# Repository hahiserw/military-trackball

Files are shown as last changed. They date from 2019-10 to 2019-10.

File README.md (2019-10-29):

# Military trackball

## Main document - main.pdf

## Youtube demo
demo01 (http://www.youtube.com/watch?v=cAlvmEIusnU)
demo02 (http://www.youtube.com/watch?v=nhbZiIEDlQE)

## Gallery

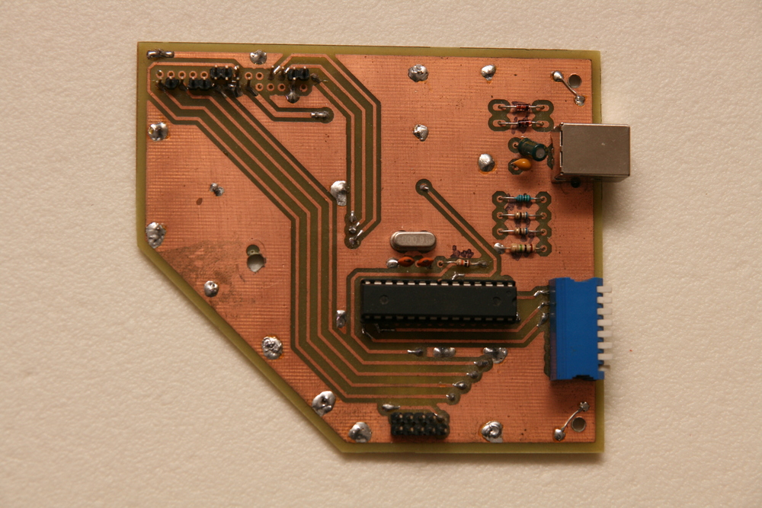
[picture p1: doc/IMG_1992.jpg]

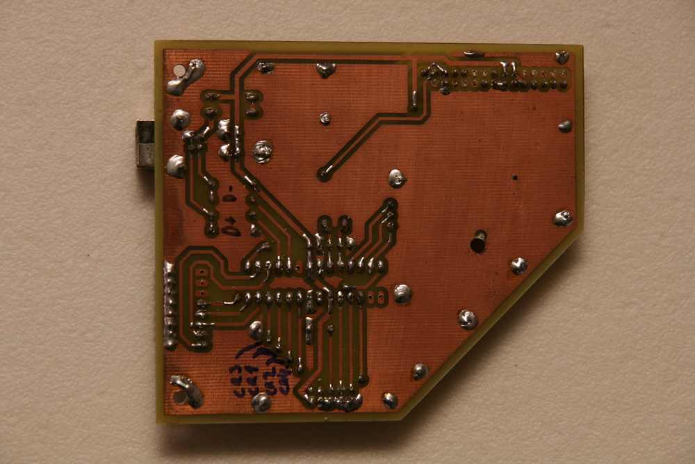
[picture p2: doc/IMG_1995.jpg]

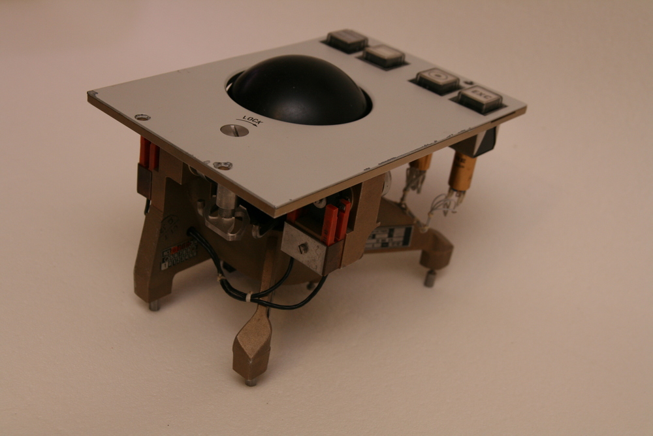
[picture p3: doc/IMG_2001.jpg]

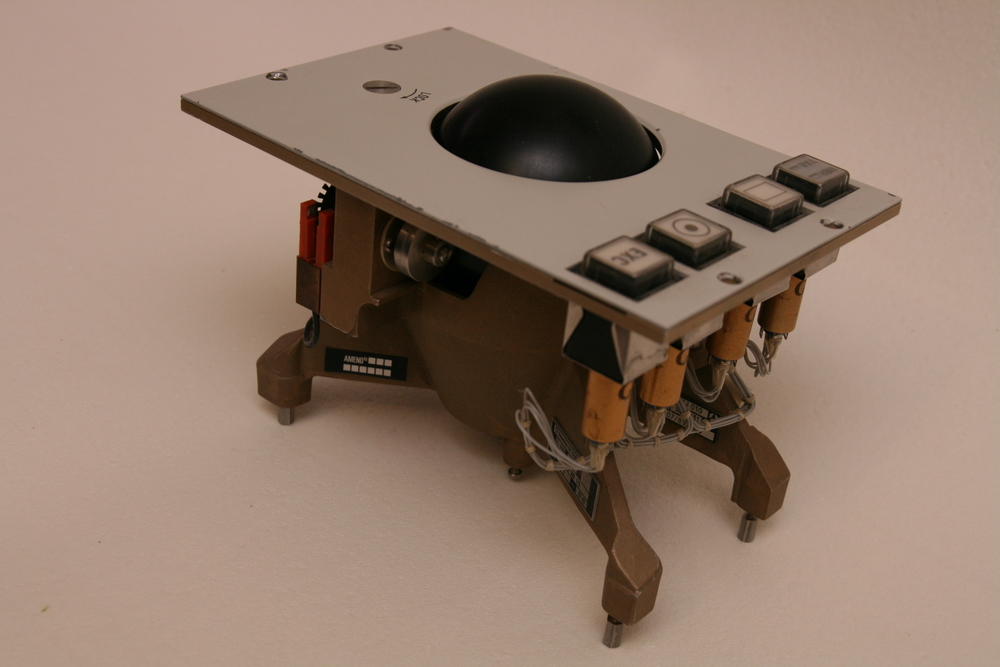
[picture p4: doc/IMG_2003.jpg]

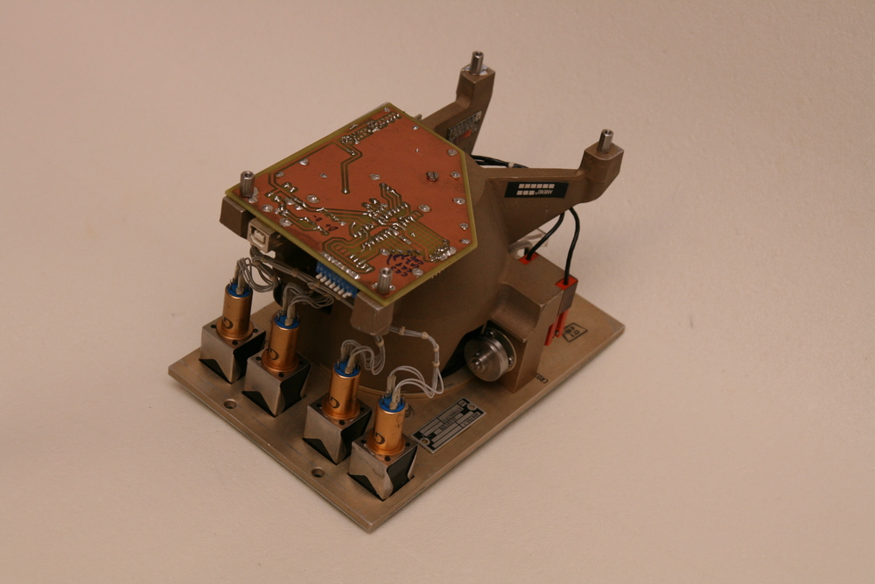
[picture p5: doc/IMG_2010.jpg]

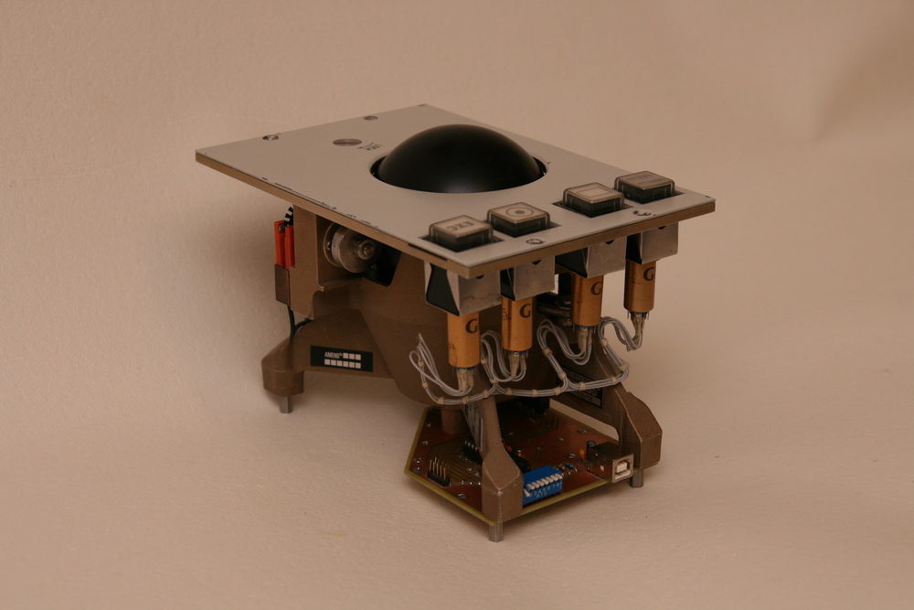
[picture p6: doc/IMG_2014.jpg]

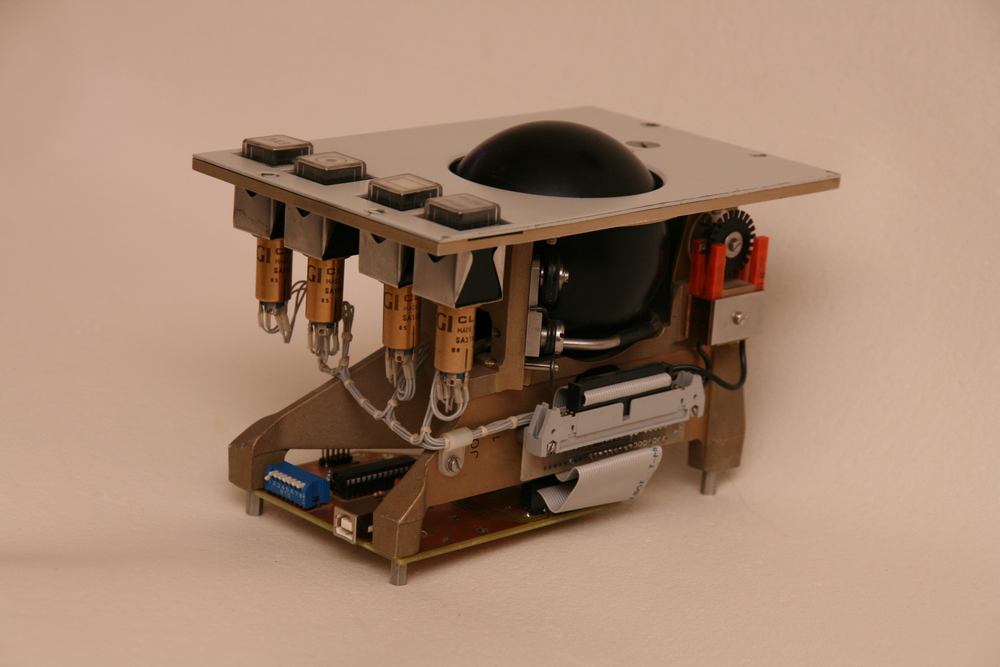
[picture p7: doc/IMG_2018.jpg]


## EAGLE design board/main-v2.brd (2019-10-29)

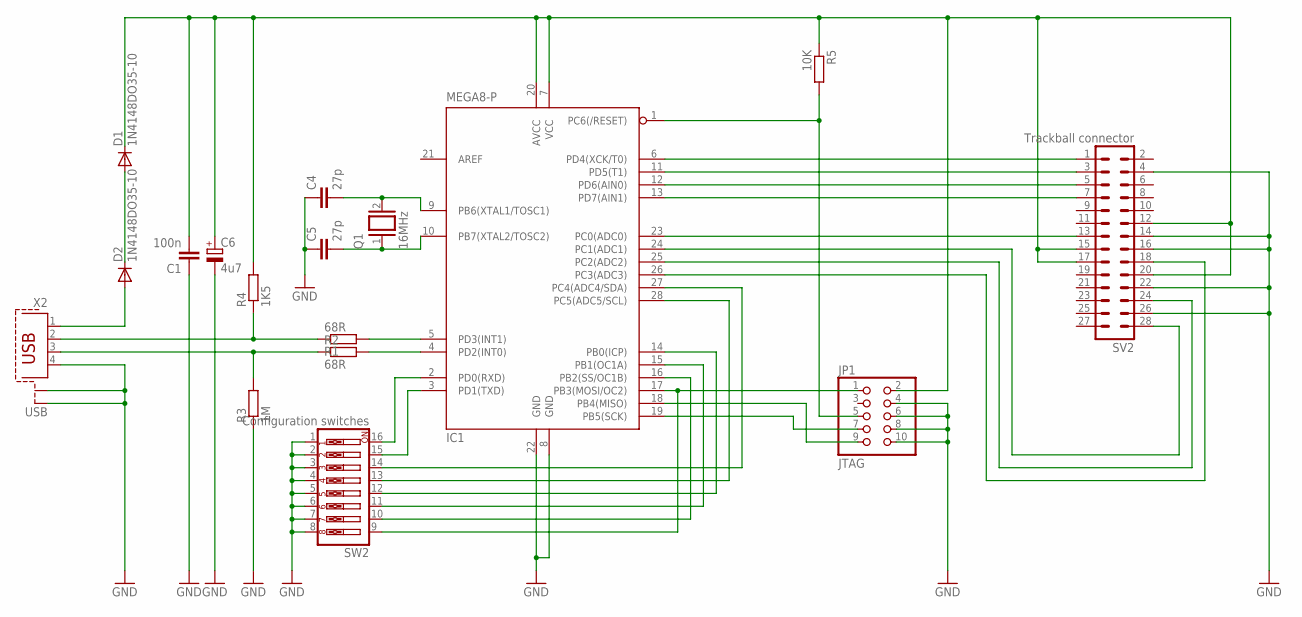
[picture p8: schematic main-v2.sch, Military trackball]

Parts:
C1: 100n; C025-025X050
C4, C5: 27p; C025-025X050
C6: 4u7; E2,5-5
D1, D2: 1N4148DO35-10; DO35-10
IC1: MEGA8-P; DIL28-3
JP1: JTAG; 2X05
Q1: 16MHz; QS
R1, R2: 68R; 0207/10
R3: 1M; 0207/10
R4: 1K5; 0207/10
R5: 10K; 0207/10
SV2: Trackball connector; MA14-2
SW2: Configuration switches; EDG-08
X2: USB; PN61729-S

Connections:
GND: C1.1, C4.1, C5.1, C6.-, IC1.8 (GND), IC1.22 (GND), JP1.4, JP1.6, JP1.8, JP1.10, R3.1, SV2.4, SV2.14, SV2.16, SV2.22, SV2.26, SW2.1, SW2.2, SW2.3, SW2.4, SW2.5, SW2.6, SW2.7, SW2.8, X2.4, X2.S1, X2.S2
unnamed: D1.A, D2.C
unnamed: IC1.5 (PD3(INT1)), R1.2
unnamed: IC1.4 (PD2(INT0)), R2.2
unnamed: R1.1, R4.1, X2.2
unnamed: R2.1, R3.2, X2.3
unnamed: IC1.12 (PD6(AIN0)), SV2.5
unnamed: C5.2, IC1.10 (PB7(XTAL2/TOSC2)), Q1.1
unnamed: C4.2, IC1.9 (PB6(XTAL1/TOSC1)), Q1.2
unnamed: IC1.11 (PD5(T1)), SV2.3
unnamed: IC1.6 (PD4(XCK/T0)), SV2.1
unnamed: IC1.23 (PC0(ADC0)), SV2.13
unnamed: IC1.13 (PD7(AIN1)), SV2.7
unnamed: IC1.25 (PC2(ADC2)), SV2.24
unnamed: IC1.26 (PC3(ADC3)), SV2.18
unnamed: IC1.1 (PC6(/RESET)), JP1.5, R5.2
unnamed: IC1.18 (PB4(MISO)), JP1.9
unnamed: IC1.19 (PB5(SCK)), JP1.7
unnamed: IC1.17 (PB3(MOSI/OC2)), JP1.1, SW2.9
unnamed: IC1.24 (PC1(ADC1)), SV2.28
unnamed: D2.A, X2.1
unnamed: IC1.16 (PB2(SS/OC1B)), SW2.10
unnamed: IC1.15 (PB1(OC1A)), SW2.11
unnamed: IC1.14 (PB0(ICP)), SW2.12
unnamed: IC1.2 (PD0(RXD)), SW2.16
unnamed: IC1.3 (PD1(TXD)), SW2.15
unnamed: IC1.27 (PC4(ADC4/SDA)), SW2.14
unnamed: IC1.28 (PC5(ADC5/SCL)), SW2.13
VCC: C1.2, C6.+, D1.C, IC1.7 (VCC), IC1.20 (AVCC), JP1.2, R4.2, R5.1, SV2.12, SV2.15, SV2.17, SV2.20

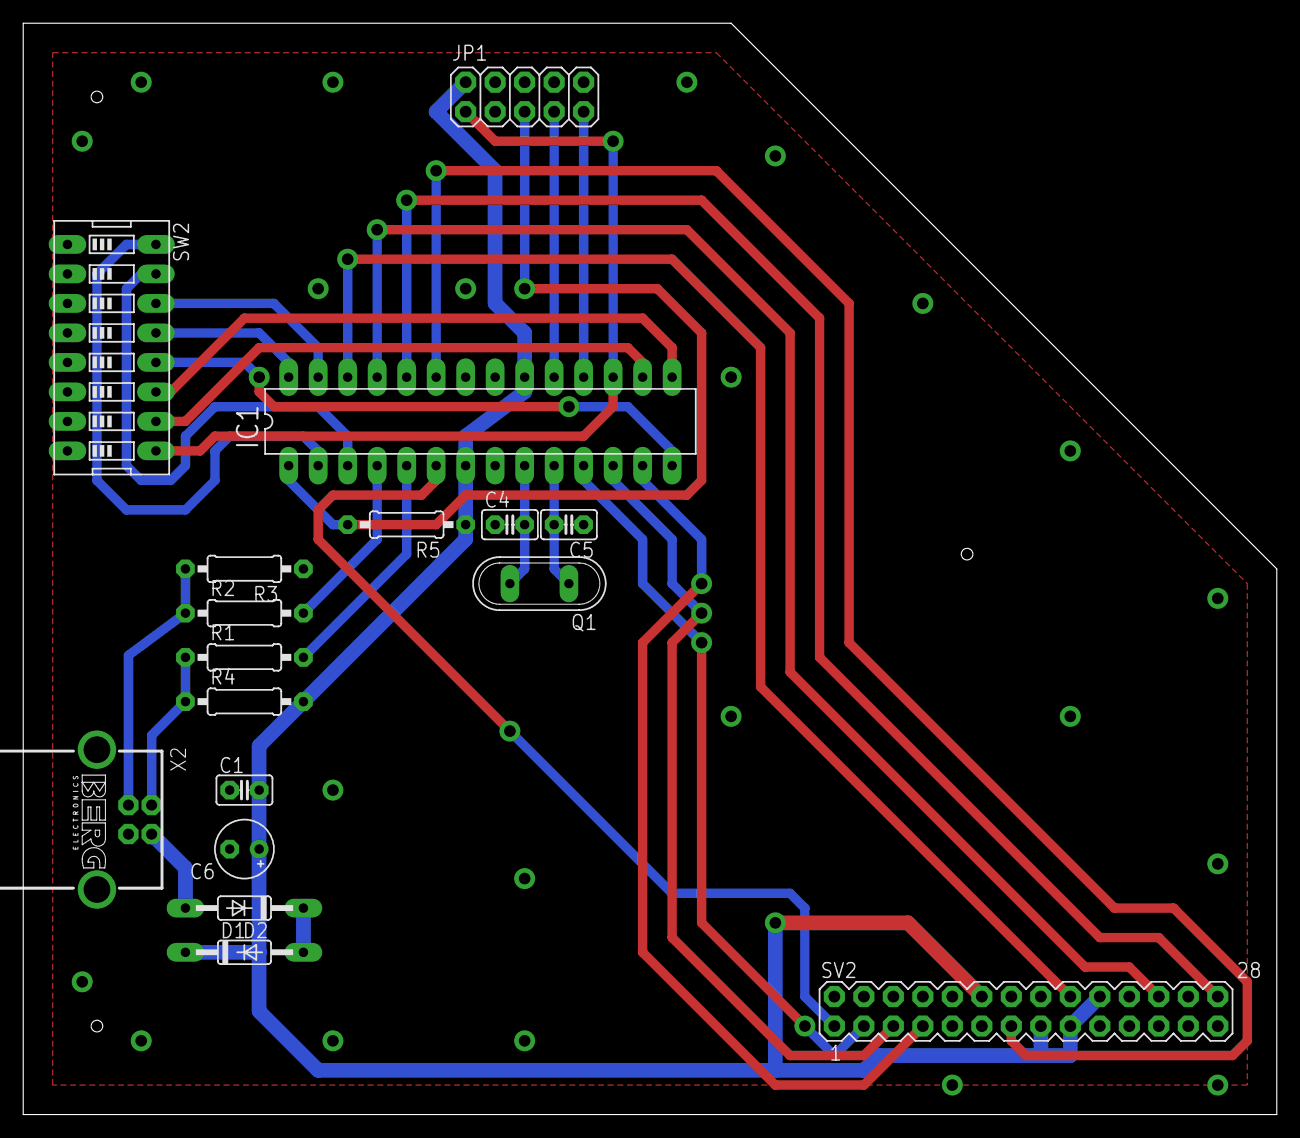
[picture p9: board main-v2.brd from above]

Board: 2 copper layers, 108.0 x 94.0 mm, 17 parts (0 on the bottom side), 29 nets.

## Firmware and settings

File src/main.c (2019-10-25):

#include <avr/io.h>
#include <avr/wdt.h>
#include <avr/interrupt.h>
#include <util/delay.h>

#include <avr/pgmspace.h> // Required by usbdrv.h
#include "usbdrv.h"


// #define SETTINGS_BUTTONS ((PIN? & 0x03) >> ?)
// // Buttons settings selected by jumpers for [rect] [circ][EXC]
// #define BUTTONS_00(v) return v;  // [L] [R][M]
// #define BUTTONS_01(v) return (v & 0x06) >> 1 & (v & 0x01) << 2 // [M] [L][R]
// #define BUTTONS_02(v) return (v & 0x04) & (v & 0x02) >> 1 & (v & 0x01) << 1 // [L] [M][R]


#define BUTTONS ( (PIND & 0xe0) >> 5 )
#define TOGGLED ( (PIND & 0x10) >> 4 )

#define CR4     ( (PINC & 0x01)      )
#define CR2     ( (PINC & 0x02) >> 1 )
#define CR1     ( (PINC & 0x04) >> 2 )
#define CR3     ( (PINC & 0x08) >> 3 )

// Configuration switches: B3 B2 B1 B0 C5 C4 D1 D0
#define CONF0   ( (PIND & 0x01)      )
#define CONF1   ( (PIND & 0x02) >> 1 )
#define CONF2   ( (PINC & 0x10) >> 4 )
#define CONF3   ( (PINC & 0x20) >> 5 )
#define CONF4   ( (PINB & 0x01)      ) // FIXME
#define CONF5   ( (PINB & 0x02) >> 1 ) // FIXME
#define CONF6   ( (PINB & 0x04) >> 2 ) // FIXME
#define CONF7   ( (PINB & 0x08) >> 3 ) // FIXME

// #define CONF7   ( 1 << PINB3 )


// #define SCROLL_STEP_DIVIDER 8
// #define SCROLL_STEP_DIVIDER ( 4 + ( (8 << CONF3) | (4 << CONF2) ) )
#define SCROLL_STEP_DIVIDER ( 2 << ( 1 << (1 << CONF3) | CONF2) )
// 16 12 8 4
// 4 + (8 4)
//
// 00010
// 00100
// 01000
// 10000

// 16 8 4 2


#define abs(a) \
	((a > 0)? a: -a)

#define clamp(a, min, max) \
	((a > max)? max: (a < min)? min: a)

// #define accelerate(x, y) \
// 	_accelerate(x); \
// 	_accelerate(y)

// #define linearity 2
#define LINEARITY ( (1 << CONF3) | CONF2 )
#define INTERSECTION 0.5

#define accelerate(x, y) \
	x = (1/(INTERSECTION+LINEARITY)) * x * (abs(x) + LINEARITY); \
	y = (1/(INTERSECTION+LINEARITY)) * y * (abs(y) + LINEARITY)

// #define _accelerate(v) \
// 	clamp(v * abs(v), -121, 121)
	// if(v > 10) \
	// 	v = 121; \
	// else if(v < -10) \
	// 	v = -121; \
	// else \
	// 	v = v * abs(v) \

#define direction(a, b, pa) \
	  ((a ^ b)? -1: 1) * ((a ^ pa)? 1: -1)


#define move(a, b, pa, pb, report_d, report_wheel, w_operation, \
	counter, enable_button) \
\
	if((a ^ pa) || (b ^ pb)) { \
		if (TOGGLED) { \
			if (scrolling_mode & enable_button \
				&& abs(counter) == SCROLL_STEP_DIVIDER) \
			{ \
				report_wheel += \
					direction(a, b, pa); \
				change = 1; \
				counter = 0; \
			} else { \
				counter += direction(a, b, pa); \
			} \
		} else { \
			report_d w_operation direction(a, b, pa); \
			change = 1; \
		} \
	}


// Report descriptor {{{
PROGMEM const char usbHidReportDescriptor[61] = {
	0x05, 0x01, // USAGE_PAGE (Generic Desktop)
	0x09, 0x02, // USAGE (Mouse)
	0xa1, 0x01, // COLLECTION (Application)

	0x09, 0x01, //   USAGE (Pointer)
	0xa1, 0x00, //   COLLECTION (Physical)

	0x05, 0x09, //     USAGE_PAGE (Button)
	0x19, 0x01, //     USAGE_MINIMUM (Button 1)
	0x29, 0x03, //     USAGE_MAXIMUM (Button 3)
	0x15, 0x00, //     LOGICAL_MINIMUM (0)
	0x25, 0x01, //     LOGICAL_MAXIMUM (1)
	0x75, 0x01, //     REPORT_SIZE (1)
	0x95, 0x03, //     REPORT_COUNT (3)
	0x81, 0x02, //     INPUT (Data, Var, Abs)
	0x75, 0x05, //     REPORT_SIZE (5)
	0x95, 0x01, //     REPORT_COUNT (1)
	0x81, 0x03, //     INPUT (Const, Var, Abs)

	0x05, 0x01, //     USAGE_PAGE (Generic Desktop)
	0x09, 0x30, //     USAGE (X)
	0x09, 0x31, //     USAGE (Y)
	0x09, 0x38, //     USAGE (Wheel)
	0x15, 0x81, //     LOGICAL_MINIMUM (-127)
	0x25, 0x7f, //     LOGICAL_MAXIMUM (127)
	0x75, 0x08, //     REPORT_SIZE (8)
	0x95, 0x03, //     REPORT_COUNT (3)
	0x81, 0x06, //     INPUT (Data, Var, Rel)

	0x05, 0x0c, //     USAGE_PAGE (Counsumer Devices)
	0x0a, 0x38, 0x02, // USAGE (AC Pan)
	0x95, 0x01, //     REPORT_COUNT (1)
	0x81, 0x06, //     INPUT (Data, Var, Rel)

	0xc0,       //   END_COLLECTION

	0xc0,       // END_COLLECTION
};


typedef struct {
	uchar buttons;
	char  dx;
	char  dy;
	char  dvwheel;
	char  dhwheel;
} report_t;


static report_t report;
static uchar idleRate;

usbMsgLen_t usbFunctionSetup(uchar data[8])
{
	usbRequest_t *rq = (void *)data;

	// The following requests are never used. But since they are required by
	// the specification, we implement them in this example.

	// class request type
	if ((rq->bmRequestType & USBRQ_TYPE_MASK) == USBRQ_TYPE_CLASS) {
		// wValue: ReportType (highbyte), ReportID (lowbyte)
		if (rq->bRequest == USBRQ_HID_GET_REPORT) {
			// we only have one report type, so don't look at wValue
			usbMsgPtr = (void *)&report;
			return sizeof(report);
		} else if (rq->bRequest == USBRQ_HID_GET_IDLE) {
			usbMsgPtr = &idleRate;
			return 1;
		} else if (rq->bRequest == USBRQ_HID_SET_IDLE) {
			idleRate = rq->wValue.bytes[1];
		}
	} else {
		// no vendor specific requests implemented
	}
	// default for not implemented requests: return no data back to host
	return 0;
}

/// }}}

static volatile uchar key_press; // mouse buttons

// SIGNAL (SIG_OUTPUT_COMPARE1A)
ISR(TIMER1_COMPA_vect)
{
	static uchar key_state;
	static uchar ct0, ct1;

	uchar i = key_state ^ ~BUTTONS;

	ct0 = ~(ct0 & i);
	ct1 =  (ct0 ^ ct1) & i;
	i &= ct0 & ct1;
	key_state ^= i;

	key_press |= key_state & i;
}

#define DEBOUNCE 200L

void timer_init()
{
	TIMSK  = 1 << OCIE1A;
	TCCR1B = (1 << CS10) | (1 << WGM12);
	// TCCR1B = (1 << CS12) | (1 << CS10) | (1 << WGM12);
	// OCR1A  = 15625;
	OCR1A  = F_CPU / DEBOUNCE;
}

// Hardware init {{{
static void hardware_init(void)
{
	wdt_enable(WDTO_1S);

	DDRD  = 0x00;
	PORTD = 0xf3; // with pull-ups

	DDRC  = 0x00; // First 4 pins - sensors; conf sw
	PORTC = 0xff; // with pull-ups

	DDRB  = 0x30; // debug, conf sw
	PORTB = 0xcf;

	usbInit();
	usbDeviceDisconnect();

	uchar i = 0;
	while (--i) {
		wdt_reset();
		_delay_ms(1);
	}

	usbDeviceConnect();

	sei();
}
// }}}



static uchar v1, v2, v3, v4, p1, p2, p3, p4;
static uchar buttons_now, buttons_prev, scrolling_mode;
static uchar change;

static char v_counter = 0;
static char h_counter = 0;

int __attribute__((noreturn)) main(void)
{
	timer_init();
	hardware_init();

	change = 0;
	buttons_prev = 0;
	scrolling_mode = 0x04;

	p1 = CR1;
	p3 = CR3;
	p2 = CR2;
	p4 = CR4;

	for (;;) {
		//PORTB = ~((PIND & 0x03) << 4);
		// PORTB = (BUTTONS & 1) << 4;
#define CS (PIND & 0x03)
		//if (CS)
		//	PORTB |= 0x20;
		//else
		//	PORTB &= ~0x20;

		wdt_reset();
		usbPoll();

		// buttons_now = BUTTONS;
		buttons_now = key_press;

		v1 = CR1;
		v3 = CR3;
		v2 = CR2;
		v4 = CR4;

		if (buttons_prev != buttons_now) {
			key_press = 0; // Breaks click and hold, modification of debouncing algorithm needed
			// I hope no one will press toggle with other buttons
			// pressed
			if(TOGGLED) {
				// change scrolling mode
				// modes: only-horizontal, only-vertical, both
				if(buttons_now & 0x07) {
					scrolling_mode = buttons_now;
					v_counter = h_counter = SCROLL_STEP_DIVIDER;
				}
			} else {
				report.buttons = buttons_now;
				change = 1;
			}
		}

		move(v1, v3, p1, p3, report.dx, report.dhwheel, +=, h_counter, 0x06);
		move(v2, v4, p2, p4, report.dy, report.dvwheel, -= ,v_counter, 0x05);

		PORTB |= change << 4;

		buttons_prev = buttons_now;

		p1 = v1;
		p2 = v2;
		p3 = v3;
		p4 = v4;

		if (change && usbInterruptIsReady()) {
			if (!CONF0) {
				accelerate(report.dx, report.dy);
			}

			usbSetInterrupt((void *)&report, sizeof(report));

			report.dx      = 0;
			report.dy      = 0;
			report.dvwheel = 0;
			report.dhwheel = 0;

			change = 0;
			// PORTB &= ~0x10;
		}
	}
}

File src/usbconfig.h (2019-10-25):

/* Name: usbconfig.h
 * Project: V-USB, virtual USB port for Atmel's(r) AVR(r) microcontrollers
 * Author: Christian Starkjohann
 * Creation Date: 2005-04-01
 * Tabsize: 4
 * Copyright: (c) 2005 by OBJECTIVE DEVELOPMENT Software GmbH
 * License: GNU GPL v2 (see License.txt), GNU GPL v3 or proprietary (CommercialLicense.txt)
 */

#ifndef __usbconfig_h_included__
#define __usbconfig_h_included__

/*
General Description:
This file is an example configuration (with inline documentation) for the USB
driver. It configures V-USB for USB D+ connected to Port D bit 2 (which is
also hardware interrupt 0 on many devices) and USB D- to Port D bit 4. You may
wire the lines to any other port, as long as D+ is also wired to INT0 (or any
other hardware interrupt, as long as it is the highest level interrupt, see
section at the end of this file).
+ To create your own usbconfig.h file, copy this file to your project's
+ firmware source directory) and rename it to "usbconfig.h".
+ Then edit it accordingly.
*/

/* ---------------------------- Hardware Config ---------------------------- */

#define USB_CFG_IOPORTNAME      D
/* This is the port where the USB bus is connected. When you configure it to
 * "B", the registers PORTB, PINB and DDRB will be used.
 */
#define USB_CFG_DMINUS_BIT      3
/* This is the bit number in USB_CFG_IOPORT where the USB D- line is connected.
 * This may be any bit in the port.
 */
#define USB_CFG_DPLUS_BIT       2
/* This is the bit number in USB_CFG_IOPORT where the USB D+ line is connected.
 * This may be any bit in the port. Please note that D+ must also be connected
 * to interrupt pin INT0! [You can also use other interrupts, see section
 * "Optional MCU Description" below, or you can connect D- to the interrupt, as
 * it is required if you use the USB_COUNT_SOF feature. If you use D- for the
 * interrupt, the USB interrupt will also be triggered at Start-Of-Frame
 * markers every millisecond.]
 */
#define USB_CFG_CLOCK_KHZ       (F_CPU/1000)
/* Clock rate of the AVR in kHz. Legal values are 12000, 12800, 15000, 16000,
 * 16500, 18000 and 20000. The 12.8 MHz and 16.5 MHz versions of the code
 * require no crystal, they tolerate +/- 1% deviation from the nominal
 * frequency. All other rates require a precision of 2000 ppm and thus a
 * crystal!
 * Since F_CPU should be defined to your actual clock rate anyway, you should
 * not need to modify this setting.
 */
#define USB_CFG_CHECK_CRC       0
/* Define this to 1 if you want that the driver checks integrity of incoming
 * data packets (CRC checks). CRC checks cost quite a bit of code size and are
 * currently only available for 18 MHz crystal clock. You must choose
 * USB_CFG_CLOCK_KHZ = 18000 if you enable this option.
 */

/* ----------------------- Optional Hardware Config ------------------------ */

/* #define USB_CFG_PULLUP_IOPORTNAME   D */
/* If you connect the 1.5k pullup resistor from D- to a port pin instead of
 * V+, you can connect and disconnect the device from firmware by calling
 * the macros usbDeviceConnect() and usbDeviceDisconnect() (see usbdrv.h).
 * This constant defines the port on which the pullup resistor is connected.
 */
/* #define USB_CFG_PULLUP_BIT          4 */
/* This constant defines the bit number in USB_CFG_PULLUP_IOPORT (defined
 * above) where the 1.5k pullup resistor is connected. See description
 * above for details.
 */

/* --------------------------- Functional Range ---------------------------- */
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
